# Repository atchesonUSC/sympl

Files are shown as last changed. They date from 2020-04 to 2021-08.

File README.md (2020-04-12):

# TaCL
TaCL project source material

Directories:

------------------

1. code_base

Contents:

1. BlocksToLogic.py - Interprets NFC-transmitted data to block logic.

2. LogicToProgram.py - Interprets block logic file created in BlocksToLogic.py, formats program file in C.

3. CompileUpload.py - Compiles the C file, flashes onto Arduino board.

4. variableClass.py - Variable representation class, provides scoping functionality for variable appearances in program.

5. Main.py - contains main program loop and operations.

6. CheckLogic.py - Contains error-scanning features that analyze the block logic file for potential errors.

--------------------

2. Training Modules

Contents:

1. TO BE COMPLETED

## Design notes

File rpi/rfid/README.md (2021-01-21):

# Overview

This repo contains the code for handling management of RFID readers
from the raspberry pi.

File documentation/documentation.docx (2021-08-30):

An Exploration into the Role of Touch in Computer Programming

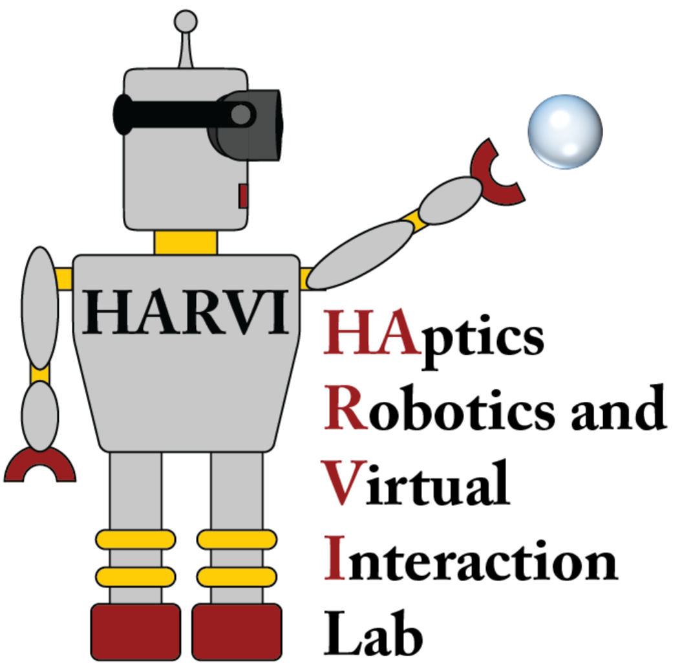
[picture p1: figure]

Official Project Documentation

Organization: HaRVI Lab

Director: Heather Culbertson, PhD

I. Preamble

Welcome! The purpose of this document is to provide an overview of our tactile coding project. Namely, it will cover the locations of project resources, materials, and will detail the remaining assembly required for project completion. The document is organized into three major sections: Overview, Resources, and Assembly. The Overview section will offer a description of the project as a whole and its intent. The Resources section details the locations of, and other sources of documentation for, project components. Lastly, the Assembly section will highlight the current state of the project and will cover the remaining steps for finishing the implementation of the project.

If at any point you should have questions regarding the content of this or other project documentation, please don’t hesitate to reach out to either Heather Culbertson (hculbert@usc.edu) or Alex Atcheson (saatcheson@gmail.com) for clarification or assistance.

II. OVERVIEW

In this section, we will briefly discuss the goal of the project and the programming tool under construction. Moreover, we will cover the workflow that programmers will encounter when using the novel programming tool.

The genesis for this project is all about understanding the role that touch may play in computer programming. Namely, we are interested in exploring how individuals code through when tasked with using a tactile tool in place of digital text as a representation of computer code. As such, we have devised a novel programming environment whereby programmers use physical coding blocks, each representing a unique code construct, for writing functioning computer programs. Each of these physical coding blocks are 3-D printed elements, about the size of one’s palm, and are consist of a 3-D design on their surface. Via recognition of surface design features, programmers might rely on touch-related stimuli for informing coding practice, an anticipated question of this project.

The system functions as follows: A user would sit down at a desk with the programming tool resting on the desk in front of them. The programming tool is a box shape and can be easily reached in the sitting the position. Next to the box on the table are a variety of coding blocks that the individual can use for writing their own program. Once ready, the individual can begin placing the coding blocks on the interactive area of the programming tool in a sequential order, nearly identical to how one would write text-based code. Once the individual has written completed their program by arranging the coding blocks on the interactive space of the programming tool, they may press the programming tool’s “Run” button for executing their program.

One of the potential target audiences for a tool such as this would be for those individuals who experience some form of visual impairment, lending added difficulty to the task of coding. As such, the programming tool uses non-visual output as a method for signifying successful or unsuccessful program execution, removing the need for sight. To support non-visual output, the programming tool relies on a speaker system for conveying messages and auditory signals to the programmer.

In summary, the system flow would allow for programmers to write code by arranging physical coding blocks on the interactive space of the programming tool. When ready to execute, the programmer may press the programming tool’s “Run” button. Through the internal speaker of the programming tool, the programmer will be alerted of either successful program completion or of an error in their code.

III. RESOURCES

In this section, we will highlight the various materials associated with the project. Namely, we will cover location and organization information. The Assembly section will cover construction steps for completing the project; as such, any build-related information will not be covered here.

High-Level Description

The programming tool works using a combination of hardware and software features. The programming tool has been designed and built entirely from scratch, which means that the hardware and software elements have been curated for the purposes of the programming tool. The below subsections will offer a breakdown of these hardware and software elements.

GitHub

The GitHub repository, titled sympl, houses all the non-hardware project materials. This includes items such as source code, technical drawings, design files, user study design, and Raspberry Pi configuration files. A pointer to the repository can be found here: https://github.com/atchesonUSC/sympl.

To clone this repository onto your local machine, you can click the green “Code” button on the repository home page, copy the SSH or HTTPS link to your clipboard, and run the following command from your command line to clone the repository folder to the directory of choosing:

$ git clone git@github.com:atchesonUSC/sympl.git

Repository Breakdown

The root of the repository consists of a README file and several directories. For increased clarity regarding the structure of the directory hierarchy, each directory consists of a README file describing its contents and related purpose. Please refer to these README files for getting sense for the contents of each directory.

1. design
  a. 3d_print
    i. gcode

Source code files for printing blocks on the Prusa extrusion printer.

  b. laser_cut

Files for upload to the Glowforge application for cutting.

  c. cad

All CAD files for the programming tool and physical programming blocks.

  d. tech_drawings

Technical drawings of the board components containing dimension information.

2. documentation

Informational material on the project.

  a. pics

Project pictures and related media.

3. old

Decommissioned materials, not in use.

4. rpi

Materials related to configuration and setup of Raspberry Pi.

  a. overlays

Device tree patches that allow for adjusting the number of available SPI chip selects.

  b. rfid

Source code for testing reading and writing capabilities of RFID reader configurations.

  c. wifi

Stores wpa_supplicant.conf files for connecting Raspberry Pi to wireless network, useful if using headless Raspberry Pi (i.e. without connecting the Pi to a computer monitor and solely operating from the command line via SSH).

5. samples

Old examples for testing the block code parser; however, these are a bit outdated and not super useful.

6. source

Contains all the source code for making the programming tool operate! main.py is the key file for running the programming tool. ParseTool.py is the second most important file, and is responsible for parsing the block code, catching and reporting errors, and formatting the lines of Python code to be written to an output file (which will be executed – this is the Python translation of the block code).

7. study

Contains information for user study design.

Project Box

The bulk of the project hardware can be found in the project cabinet located on the workshop side of the lab space. Here’s an image of the project cabinet (it is the rightmost cabinet located in the background of the image):

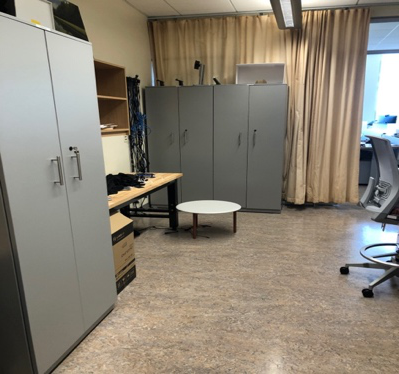
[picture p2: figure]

Upon opening the project cabinet, the project box can be found on the shelf that is second from the bottom. Here is a picture of the cardboard project box:

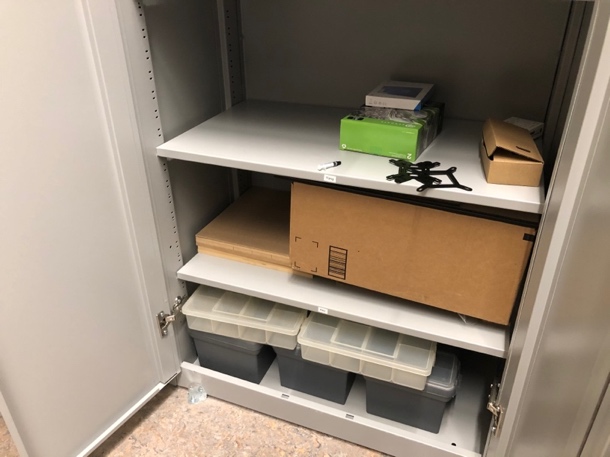
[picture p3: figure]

Other tools that might be necessary for working on the assembly (i.e., soldering iron, 3D printing materials, scissors, etc.) are organized and can be found in the workshop side of the lab space.

IV. ASSEMBLY

This section will cover the remaining assembly required for completing the programming tool. As covered in the Resources section, generally speaking, the materials required for completing the assembly can be found in the project box and the tools for doing so can be found in locations around the lab workspace. The following subsections will cover these remaining assembly steps.

Laser Cut Board Siding

The physical frame of the programming tool is constructed from several pieces of unfinished draftboard. The programming tool is in the shape of a rectangular box, and the layout of the siding is shown below:

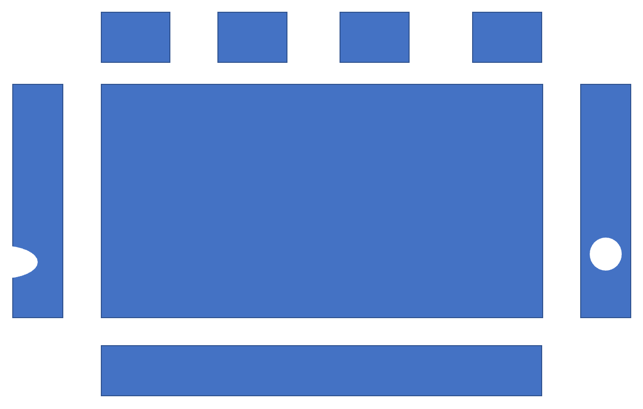
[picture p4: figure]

Of the several box pieces, the top side still needs to be cut. The outward-facing side of the top piece is where users will place and arrange blocks, whereas the inward-facing side is where the sensors and stability components will be connected. The stability components in this case are small magnets arranged on the inward-facing part of the top side. These magnets sit in small casings, as per following image:

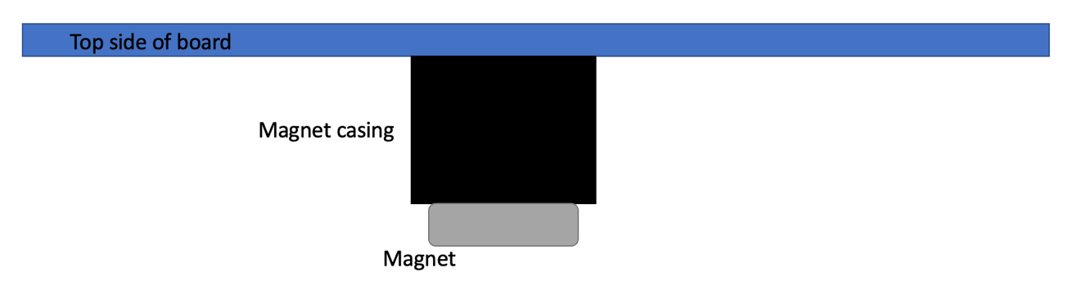
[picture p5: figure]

Located in the /sympl/design/laser_cut directory, there are two SVG files: top_side_upward.svg and top_side_inward.svg. Using a piece of draftboard from lab, the top portion of the board can be laser cut using the Glowforge (check in Sandeep for how to complete the Glowforge training). The Glowforge web app (app.glowforge.com) is where designs can be uploaded for lasering with the Glowforge. For top_side_upward.svg, set the oval shapes to be engraved and set the rectangular outline to be cut. Flip over the cut board piece and place back in the Glowforge bed. For top_side_inward.svg, set the circles to be engraved and set the outline to be ignored.

Row Division

The board consists of 4 rows, with each row supporting 6 block spaces. Dividers between the different rows should be added to reinforce the division between the different rows, as in the figure below:

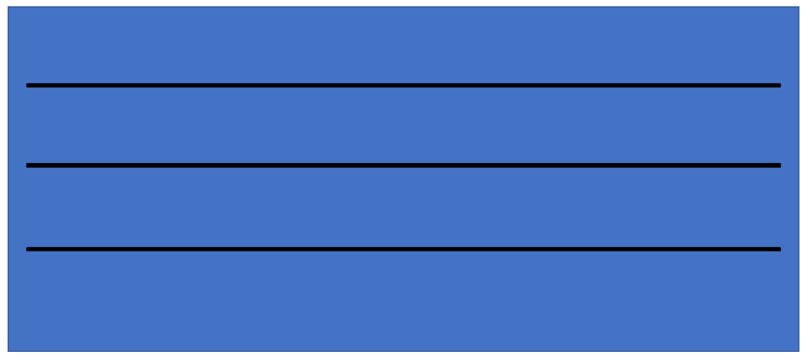
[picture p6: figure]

Three Dowel rods will work well for this, and they can be purchased on Amazon at the following page: - https://www.amazon.com/Wooden-Square-Crafts-Woodworking-Projects/dp/B07T3F18BM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"+square+rod&qid=1625078197&sr=8-4&th=1/

The dowel rods can be cut to the appropriate size and connected to the board (a little bit of hot glue should do the trick here) in such a way to separate the rows as shown in the above figure.

RFID Readers

The programming tool utilizes RFID readers to detect the presence of the programming blocks placed on the surface of the tool. One of these RFID readers, with a yellow ribbon cable connected to it, is pictured here:

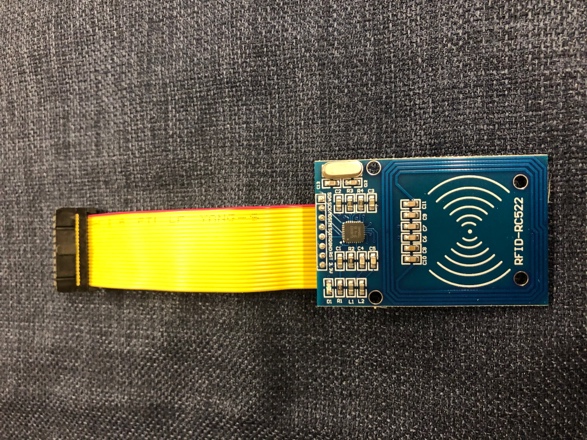
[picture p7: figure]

These RFID readers are connected to the inward-facing side of the top piece of the board box, as shown in the diagram below:

Altogether, since there are 24 total block spaces, there will be 24 total RFID readers connected to the inward-facing side of the top board piece, one for each block space. Some experimentation might be required, but some strong tape should do the trick in the way of connecting the readers to the top piece. The sensing side of the readers (shown in the picture of reader with the white markings) should be facing upward so that it can read the block sitting over its space.

Each of the RFID readers should have a yellow ribbon cable connected to their pins. Ultimately, this will allow for the readers to be easily plugged into the programming tool circuit board (a topic discussed more below).

Programming Tool Audio – Speaker

The programming tool conveys auditory output to the user via a small speaker mounted into the side of the board box. The speaker, along with its connecting cord for interfacing with the Raspberry Pi’s audio port, is pictured here:

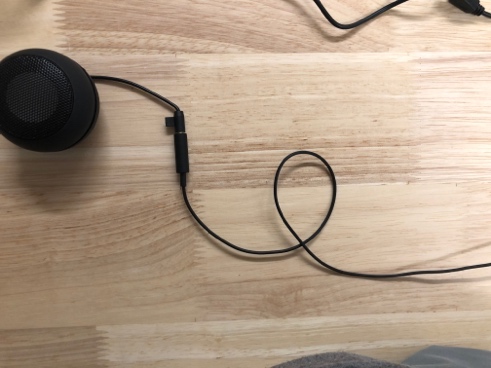
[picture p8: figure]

If twisted, the speaker can extend in length, as in the following image:

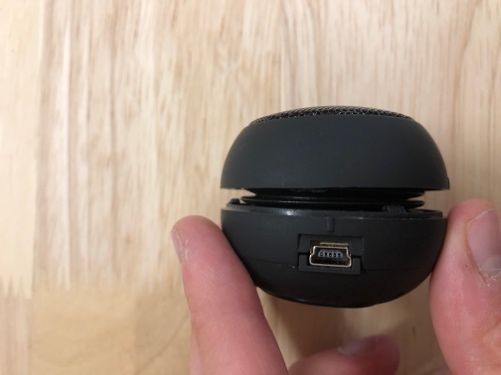
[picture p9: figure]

To insert the speaker into the board box, it is desired that the speaker be untwisted, and box side wedged in between the two ends, so that the audio-emitting portion face outward and the other portion face inward. The below figure gives a view of this design:

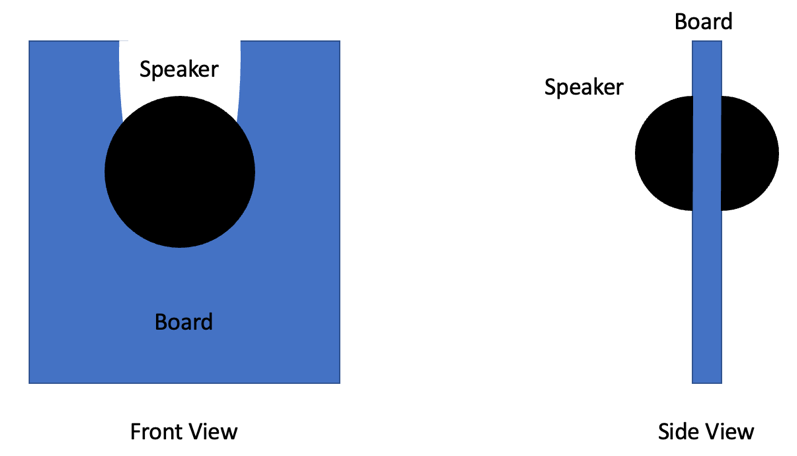
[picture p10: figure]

As shown in the diagram above, the speaker is wedged into the side piece of the board. This wedge opening must be carved out. To do this, you can take a piece of draftboard and, using the Glowforge, cut out the design entitled speaker.svg in the laser_cut folder. Once the piece has been cut, you can carve out the opening to the whole using a dremel tool in lab. This step is pictured below:

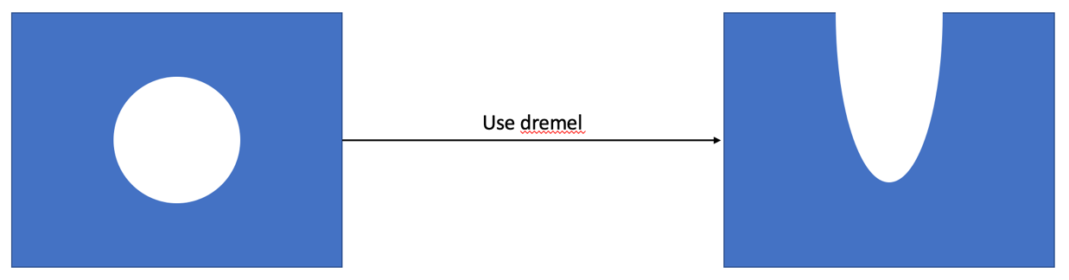
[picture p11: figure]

Magnet Casings

Magnets are used for providing a form of stability and control to block placement. These small magnets are inserted into 3D-printed casings, which are then attached to the inward-facing side of the top part of the board. An image of a magnet in its casing is shown below:

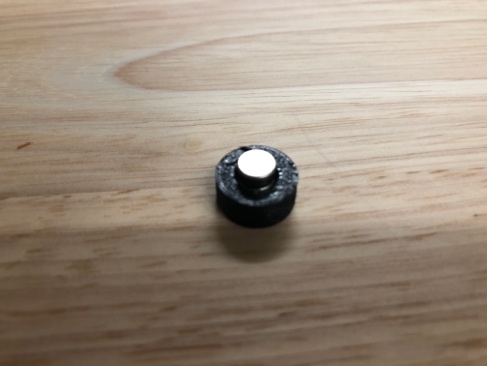
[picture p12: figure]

The magnets can potentially be secured by using hot glue. These magnet casings can be 3D printed in lab using the Prusa extrusion printer. The gcode for the magnet casing can be found in the gcode folder in the 3d_print directory. Once you have downloaded and installed the PrusaSlicer application (useful for 3D printing with our lab’s printer), you can simply use this gcode file. Here’s where you can download the PrusaSlicer tool: https://www.prusa3d.com/prusaslicer/

From the subsection Laser Cut Board Siding, it discussed the engraving process that occurs to the inward-facing side of the top board piece. These engraved holes are where the magnet casings will be connected, as illustrated in the second graphic of that section.

Compile/ Execute Button

The programming tool has a single button for executing code, which is located on the side of the tool. An image of this button is shown below:

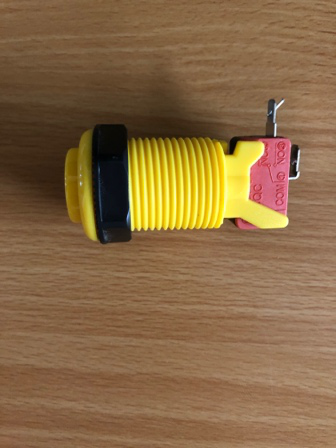
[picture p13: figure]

This button is “normally open,” which means pressing it will close the circuit.

Power Supply

To power the programming tool, it must be plugged into a wall outlet. The plug for the tool is pictured here:

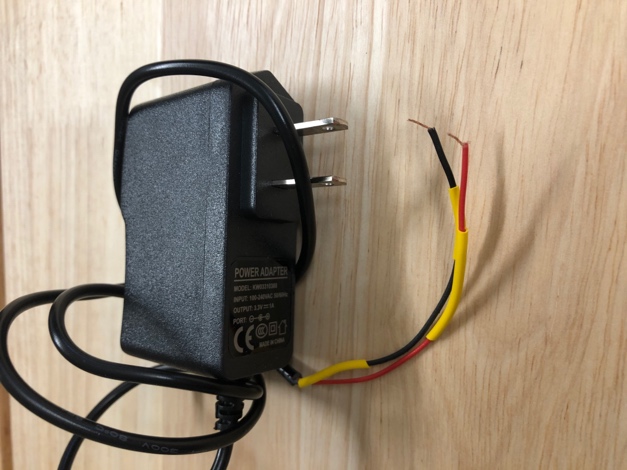
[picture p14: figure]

The red wire is for power and the black wire is for ground.

Circuit Board

The programming tool consists of several electronic components: Raspberry Pi, speaker, button, and RFID readers. The Raspberry Pi is the brains of the tool, the speaker is for auditory output, the button is executing the block code, and the RFID readers are for sensing the type and location of the blocks. Internally, these components are connected to the same circuit board.

First let’s talk about the protoboards that comprise the circuit board. Each protoboard is consists of 30 columns (with label “A” on top and “D” on the bottom) and 48 rows, as shown in the picture below:

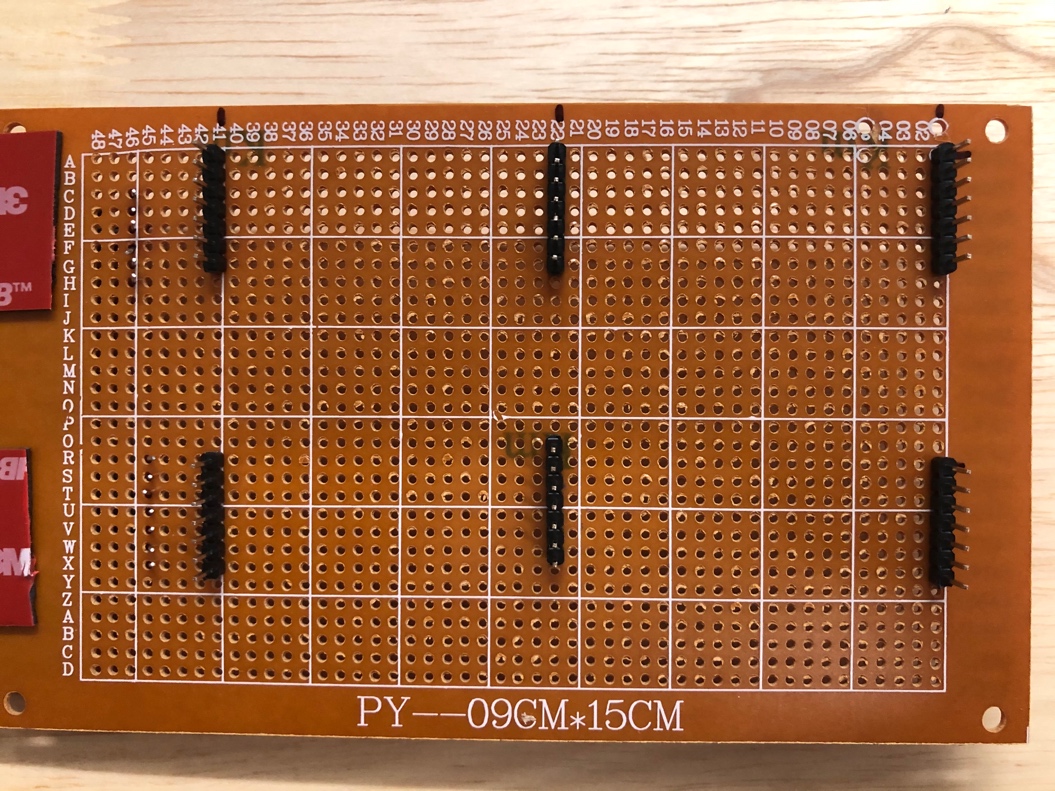
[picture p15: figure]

Each column is shorted to be a single node, meaning that all the holes in a column are connected. This makes it convenient for connecting a row of readers in parallel, where each RESET pin on a reader is connected a column designated for carrying the RESET signal, and so on.

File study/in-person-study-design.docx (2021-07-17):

Tactile Programming – Exploratory Design Evaluation Outline

Spring – Summer, 2021

Research Questions

RQ1: Are there any usability issues that impede students of mixed visual ability from reading code?

RQ2: Are there any usability issues that impede students of mixed visual ability from writing code?

RQ3: How do students of mixed visual ability trace programs?

RQ4: How do students of mixed visual ability create programs?

Participants

Target population characteristics:

- Age: 18 – 23 (Typical age range of college students)
- Major(s)/ Background: Computer Science
- Programming Experience: Participants must identify as having programming experience in some form (No strict definition used here)
- Visual Ability: Sighted (It should be noted that, roughly speaking, a single degree of sightedness should be considered, as this may impact the exploratory/ scanning abilities demonstrated by participants; sightedness controlled using blindfold)

Data Capture and Analysis

Collection strategies:

- Video
  - Camera positioned directly above programming device, facing downward onto device surface.
  - Capture participant hand movements and exploratory motions.
  - No audio capture necessary.
  - Annotations
  - QR code hand tracker
- Compiled programs
  - Store raw block code, compilation success or failure flag, and error message (if any)
    - Per-participant entry created following compilation

Tracing Programs

Working “Trace” Definition: Any physical, verbal, or visual way of describing program execution.

Tracing Sequences

- Purpose
  - Examine ability of users to interpret basic statements.
  - Consider how line continuation may impact readability.
    - Examine continuous assignment statement (all on one line) and statement that is broken across the two lines.
- Performance test:
  - Provided completed code, ask participants to describe the program execution
    - Level 1: “Assign 7 to V1”
    - Level 2: “Assign 2 to V1. Assign sum of 3 and V1 to V2”
- Time Estimate: ~ 5 minutes

Tracing Branching Logic

- Purpose:
  - Examine ability of participants to interpret branch conditions
  - Examine ability of participants to determine which branch will execute given a condition to be evaluated
- Performance test
  - Provided completed code, ask participants to describe the program execution
    - Level 1: “Assign 3 to V1. If V1 greater than 4, assign 8 to V1. Else, assign 5 to V1.”
    - Level 2: “Assign 6 to V1. If V1 less than 4, … Else if V1 less than 7, … Else, …”
- Time Estimate: ~ 5 minutes

Tracing Loops

- Purpose:
  - Examine ability of participants to interpret loop conditions
  - Examine ability of participants to trace looping over several iterations
- Performance test
  - Provided completed code, ask participants to describe the program execution
    - Level 1: “Assign 1 to V1. Loop 5 times, incrementing V1 by 1 each time”
    - Level 2: “Assign 4 to V1. Loop 8 times, incrementing V1 by 2 each time”
- Time Estimate: ~ 5 minutes

Tracing to Debug

- Purpose:
  - Examine ability of participants to find and fix program bugs, both syntactic and semantic
  - Sheds light on helpfulness of auditory feedback (error messages) and the exploratory strategies used by
- NO performance test here, just something to observe/ take note of
  - Specifically, pay special attention to annotate comments/ strategies used by participants to fix problems, also any issues that impede problem solving

Creating Programs

Create sequence

- Purpose:
  - Examine sequence-building patterns of students with mixed visual ability
- Performance test
  - Provided necessary blocks and high-level description, ask participants to write code

Create branching logic

- Purpose:
  - Examine branching-logic-building patterns of students with mixed visual ability
- Performance test
  - Provided necessary blocks and high-level description, ask participants to write code

Create loop

- Purpose:
  - Examine loop building patterns of students with mixed visual ability
- Performance test
  - Provided necessary blocks and high-level description, ask participants to write code

User Evaluation

• Evaluate characteristics of interest for tactile learning tools (refer to Inclusive Education article)

• Request that participants complete the evaluation following all performance testing

Perception | Question | Description
Joy | How fun was the programming environment? | Low values boring, high values fun
Weariness | How tired did you feel when using the programming environment? | Low values tired, high values comfortable
Usefulness | How useful did you find the programming environment? | Low values useless, high values useful
Accessibility | How accessible did you find the programming environment? | Low values inaccessible, high values accessible
Learning | Is the programming environment a good learning tool? | Low values considered bad learning tool, high values considered good learning tool
Potential Use | Do you think this system would have been helpful for you when first learning about topics such as instruction sequences, branching logic, and looping? | Low values indicate would like to use system to learn about basic programming, high values indicate would like to use system to learn about basic programming
Didactic | How didactic (learning with pleasure and entertainment) was the programming environment? | Low values indicate stultifying (stifle enthusiasm, freedom), high values indicate system conveyed meaning and pleasure
Easiness | Did you find the programming environment easy to use? | Low values indicate difficult to use system, high values indicate easy to use system

References

• Torino (https://www.tandfonline.com/doi/pdf/10.1080/07370024.2018.1512413)

• Virtual Haptic Perception as an Educational Assistive Technology: A Case Study in Inclusive Education

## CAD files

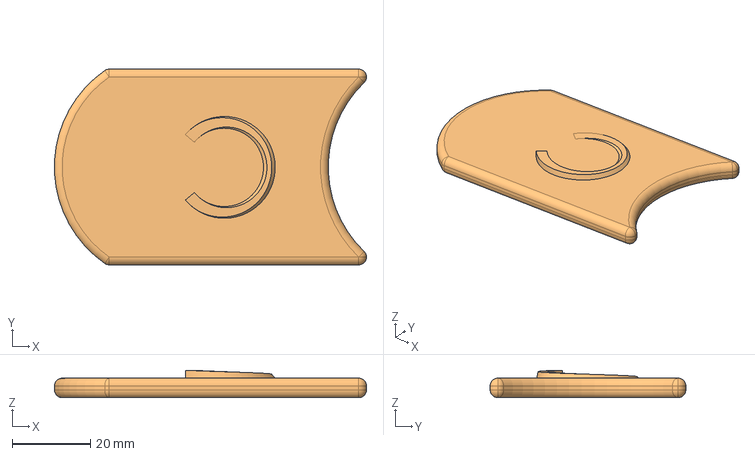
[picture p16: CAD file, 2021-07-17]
design/cad/loopblock.stp
79.7 x 50.0 x 7.00 mm

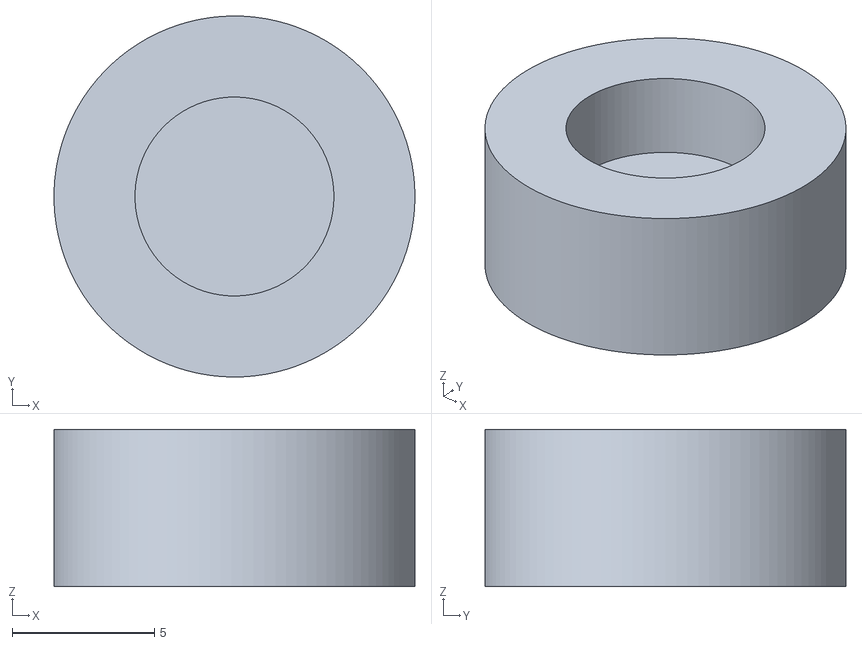
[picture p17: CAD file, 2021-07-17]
design/cad/magnet_casing.stl
12.7 x 12.7 x 5.54

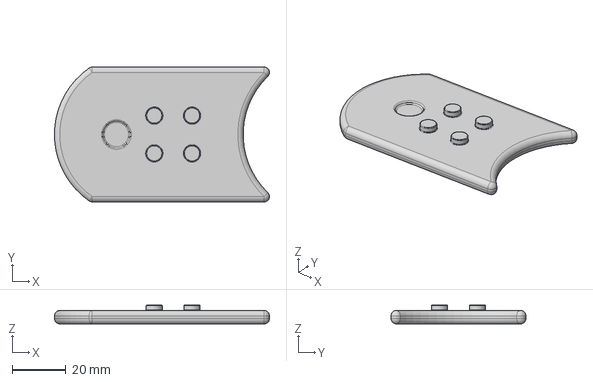
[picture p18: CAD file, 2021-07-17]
design/cad/9block.stp
79.7 x 50.0 x 7.00 mm

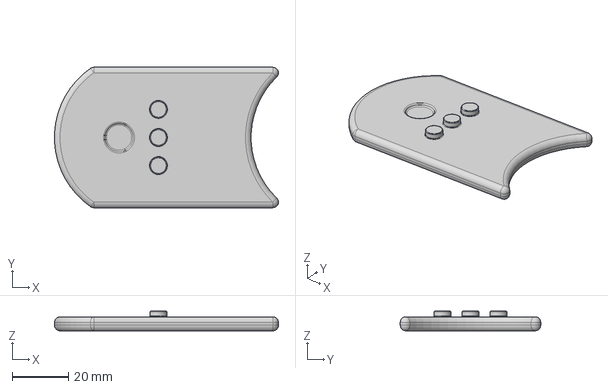
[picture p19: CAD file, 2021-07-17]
design/cad/8block.stp
79.7 x 50.0 x 7.00 mm

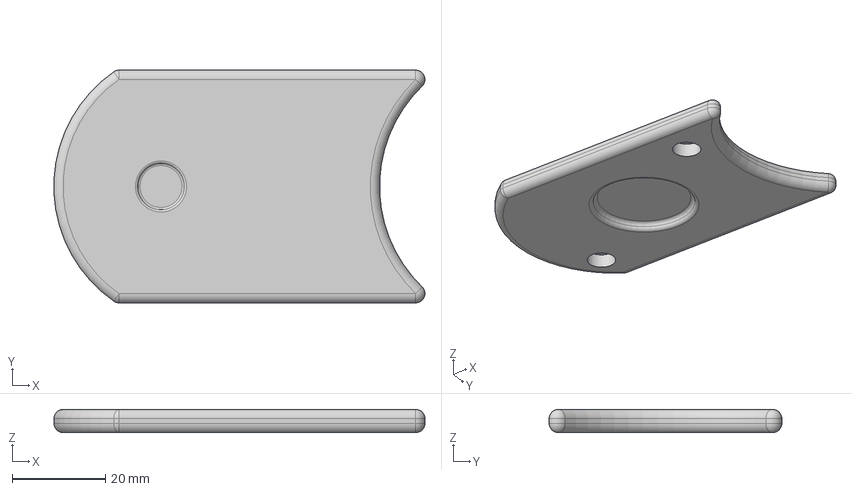
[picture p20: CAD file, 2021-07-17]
design/cad/5block.stp
79.7 x 50.0 x 5.00 mm

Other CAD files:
design/cad/assignblock.stp
design/cad/3block.stp
design/cad/greaterblock.stp
design/cad/endloopblock.stp
design/cad/2block.stp
design/cad/4block.stp
design/cad/elseifblock.stp
design/cad/ifblock.stp
design/cad/stopblock.stp
design/cad/elseblock.stp
design/cad/1block.stp
design/cad/7block.stp
design/cad/6block.stp

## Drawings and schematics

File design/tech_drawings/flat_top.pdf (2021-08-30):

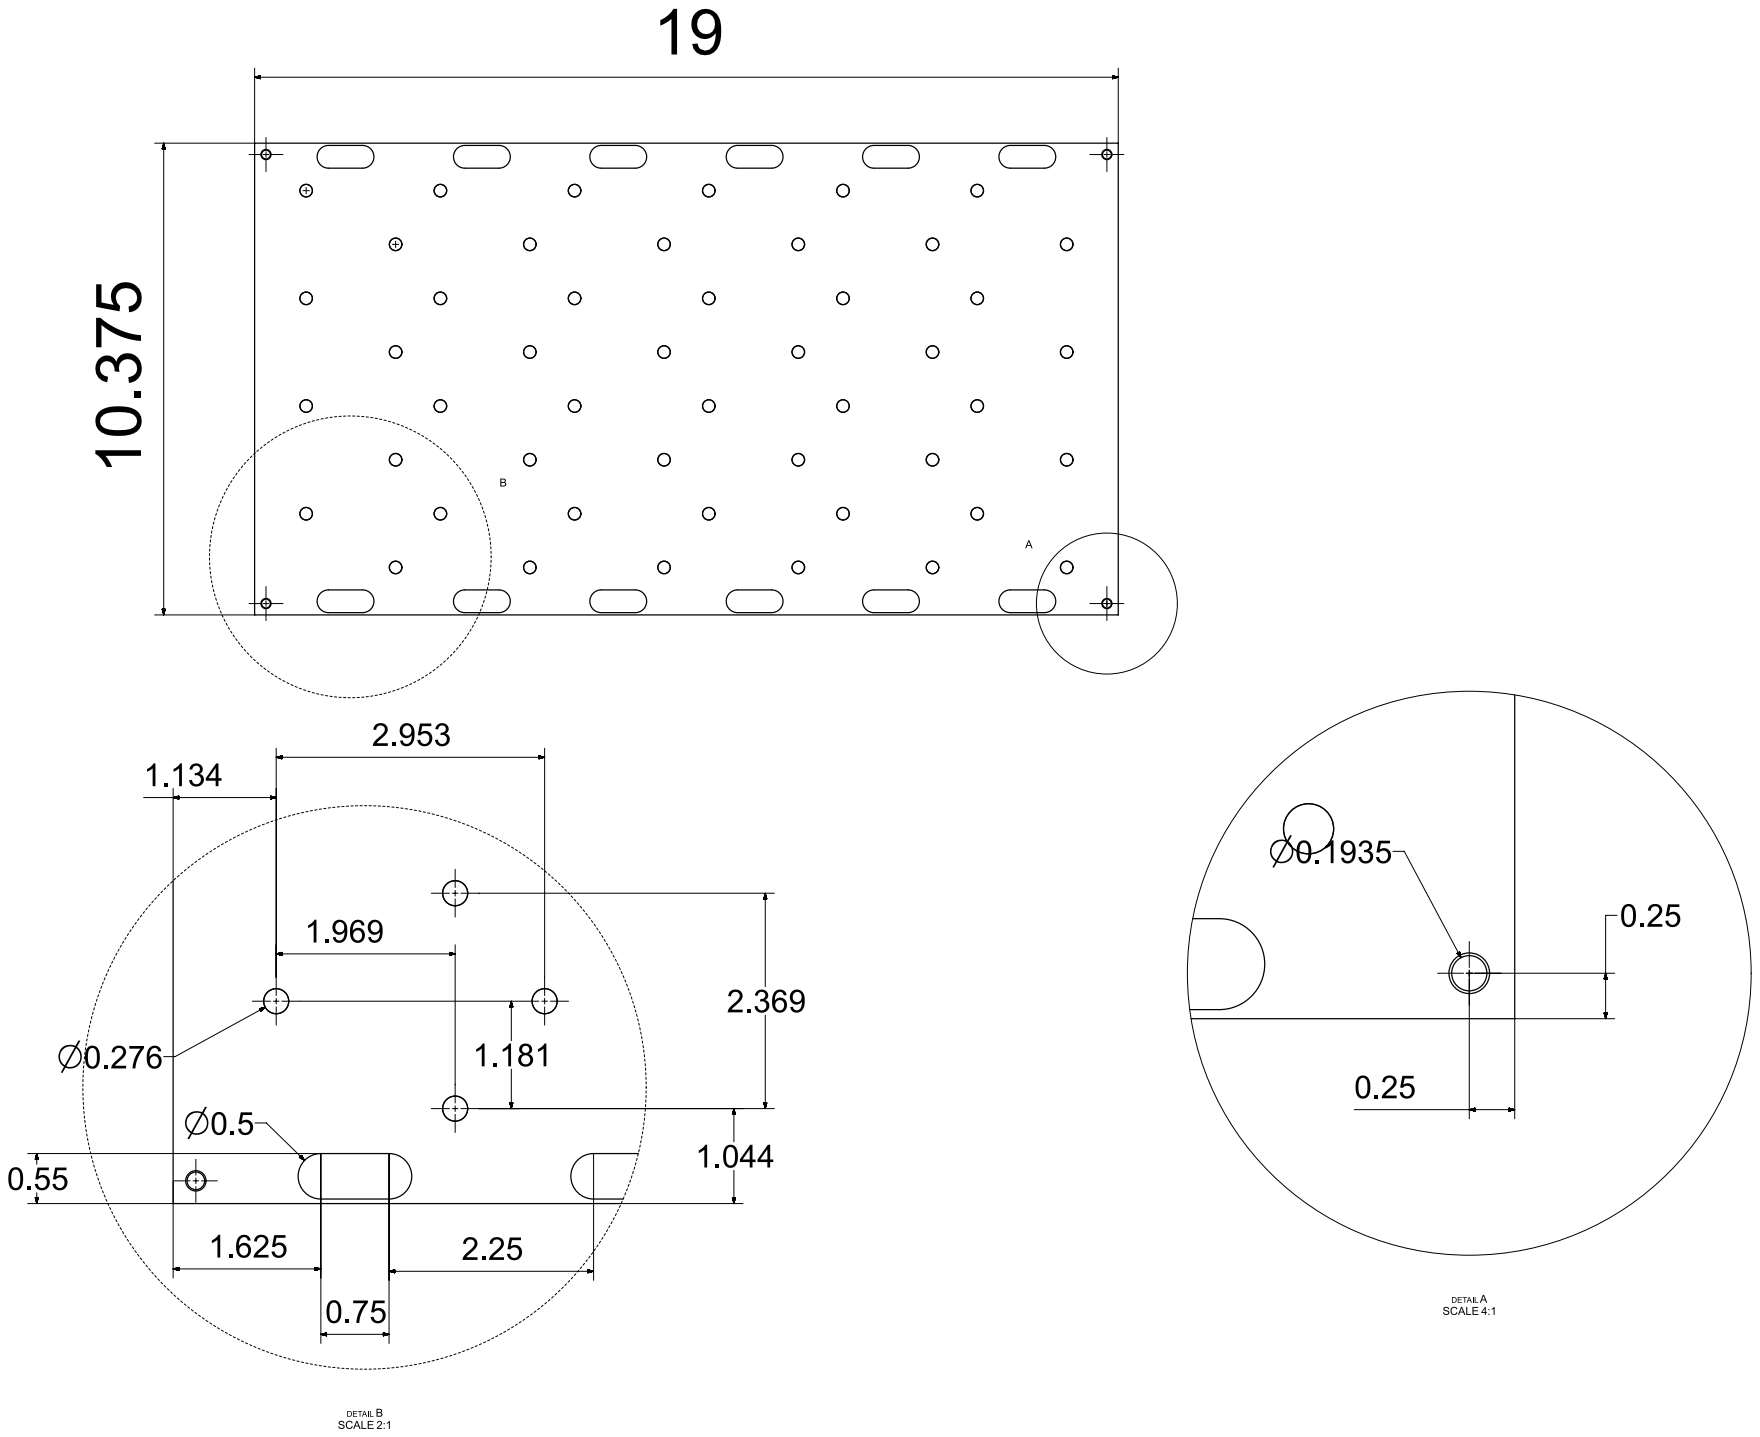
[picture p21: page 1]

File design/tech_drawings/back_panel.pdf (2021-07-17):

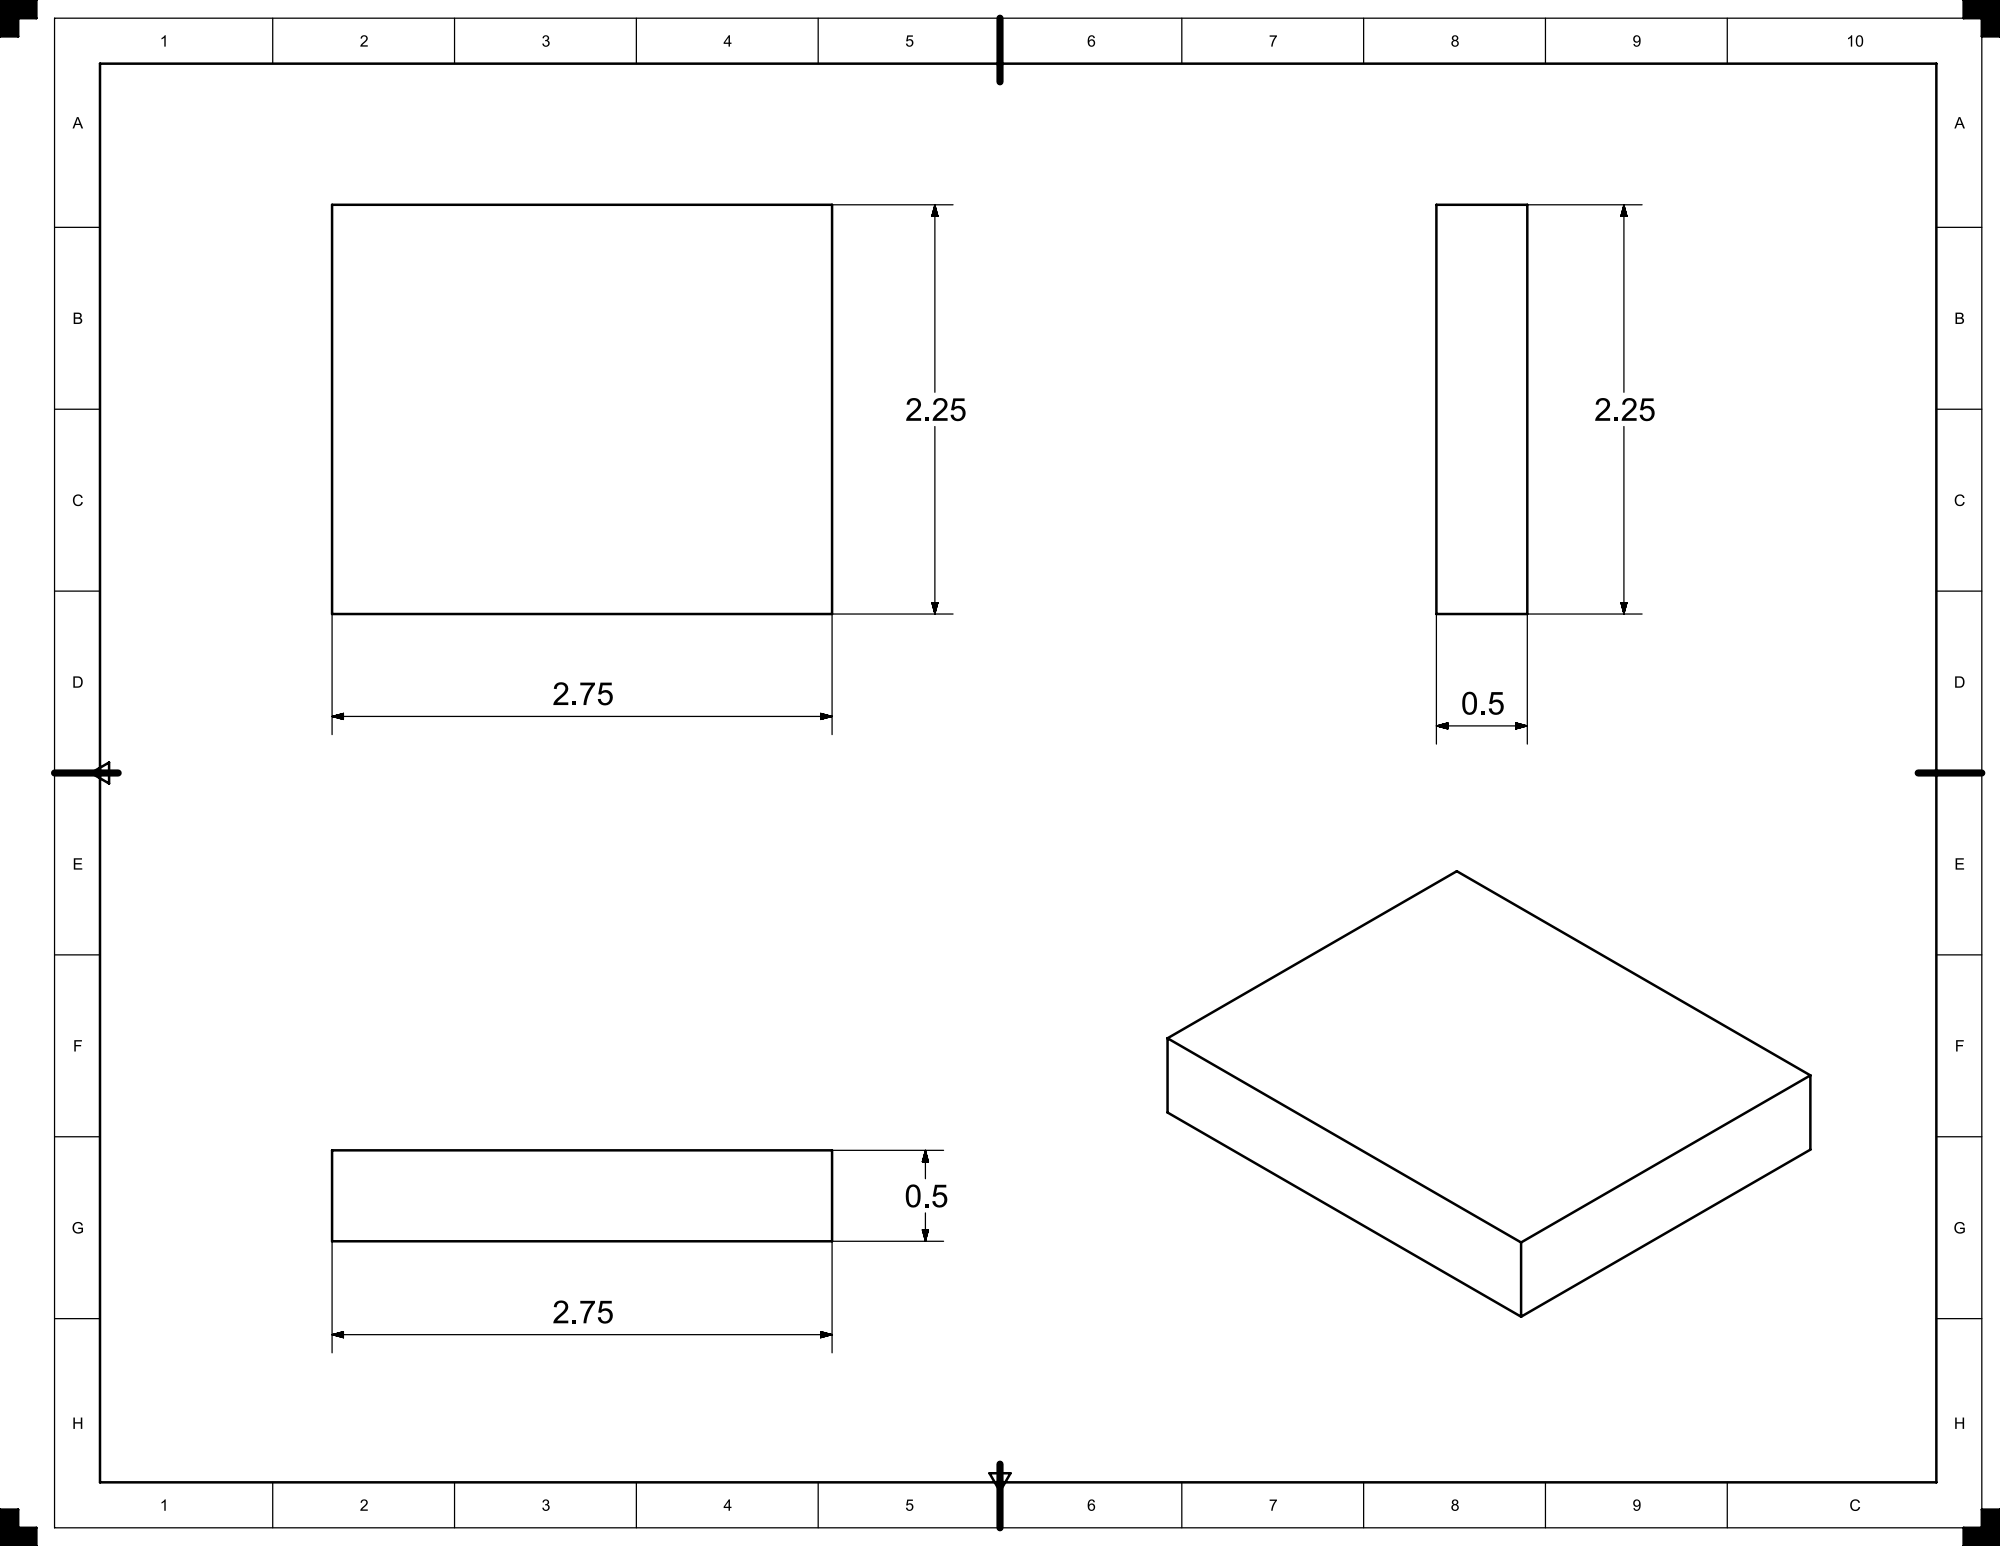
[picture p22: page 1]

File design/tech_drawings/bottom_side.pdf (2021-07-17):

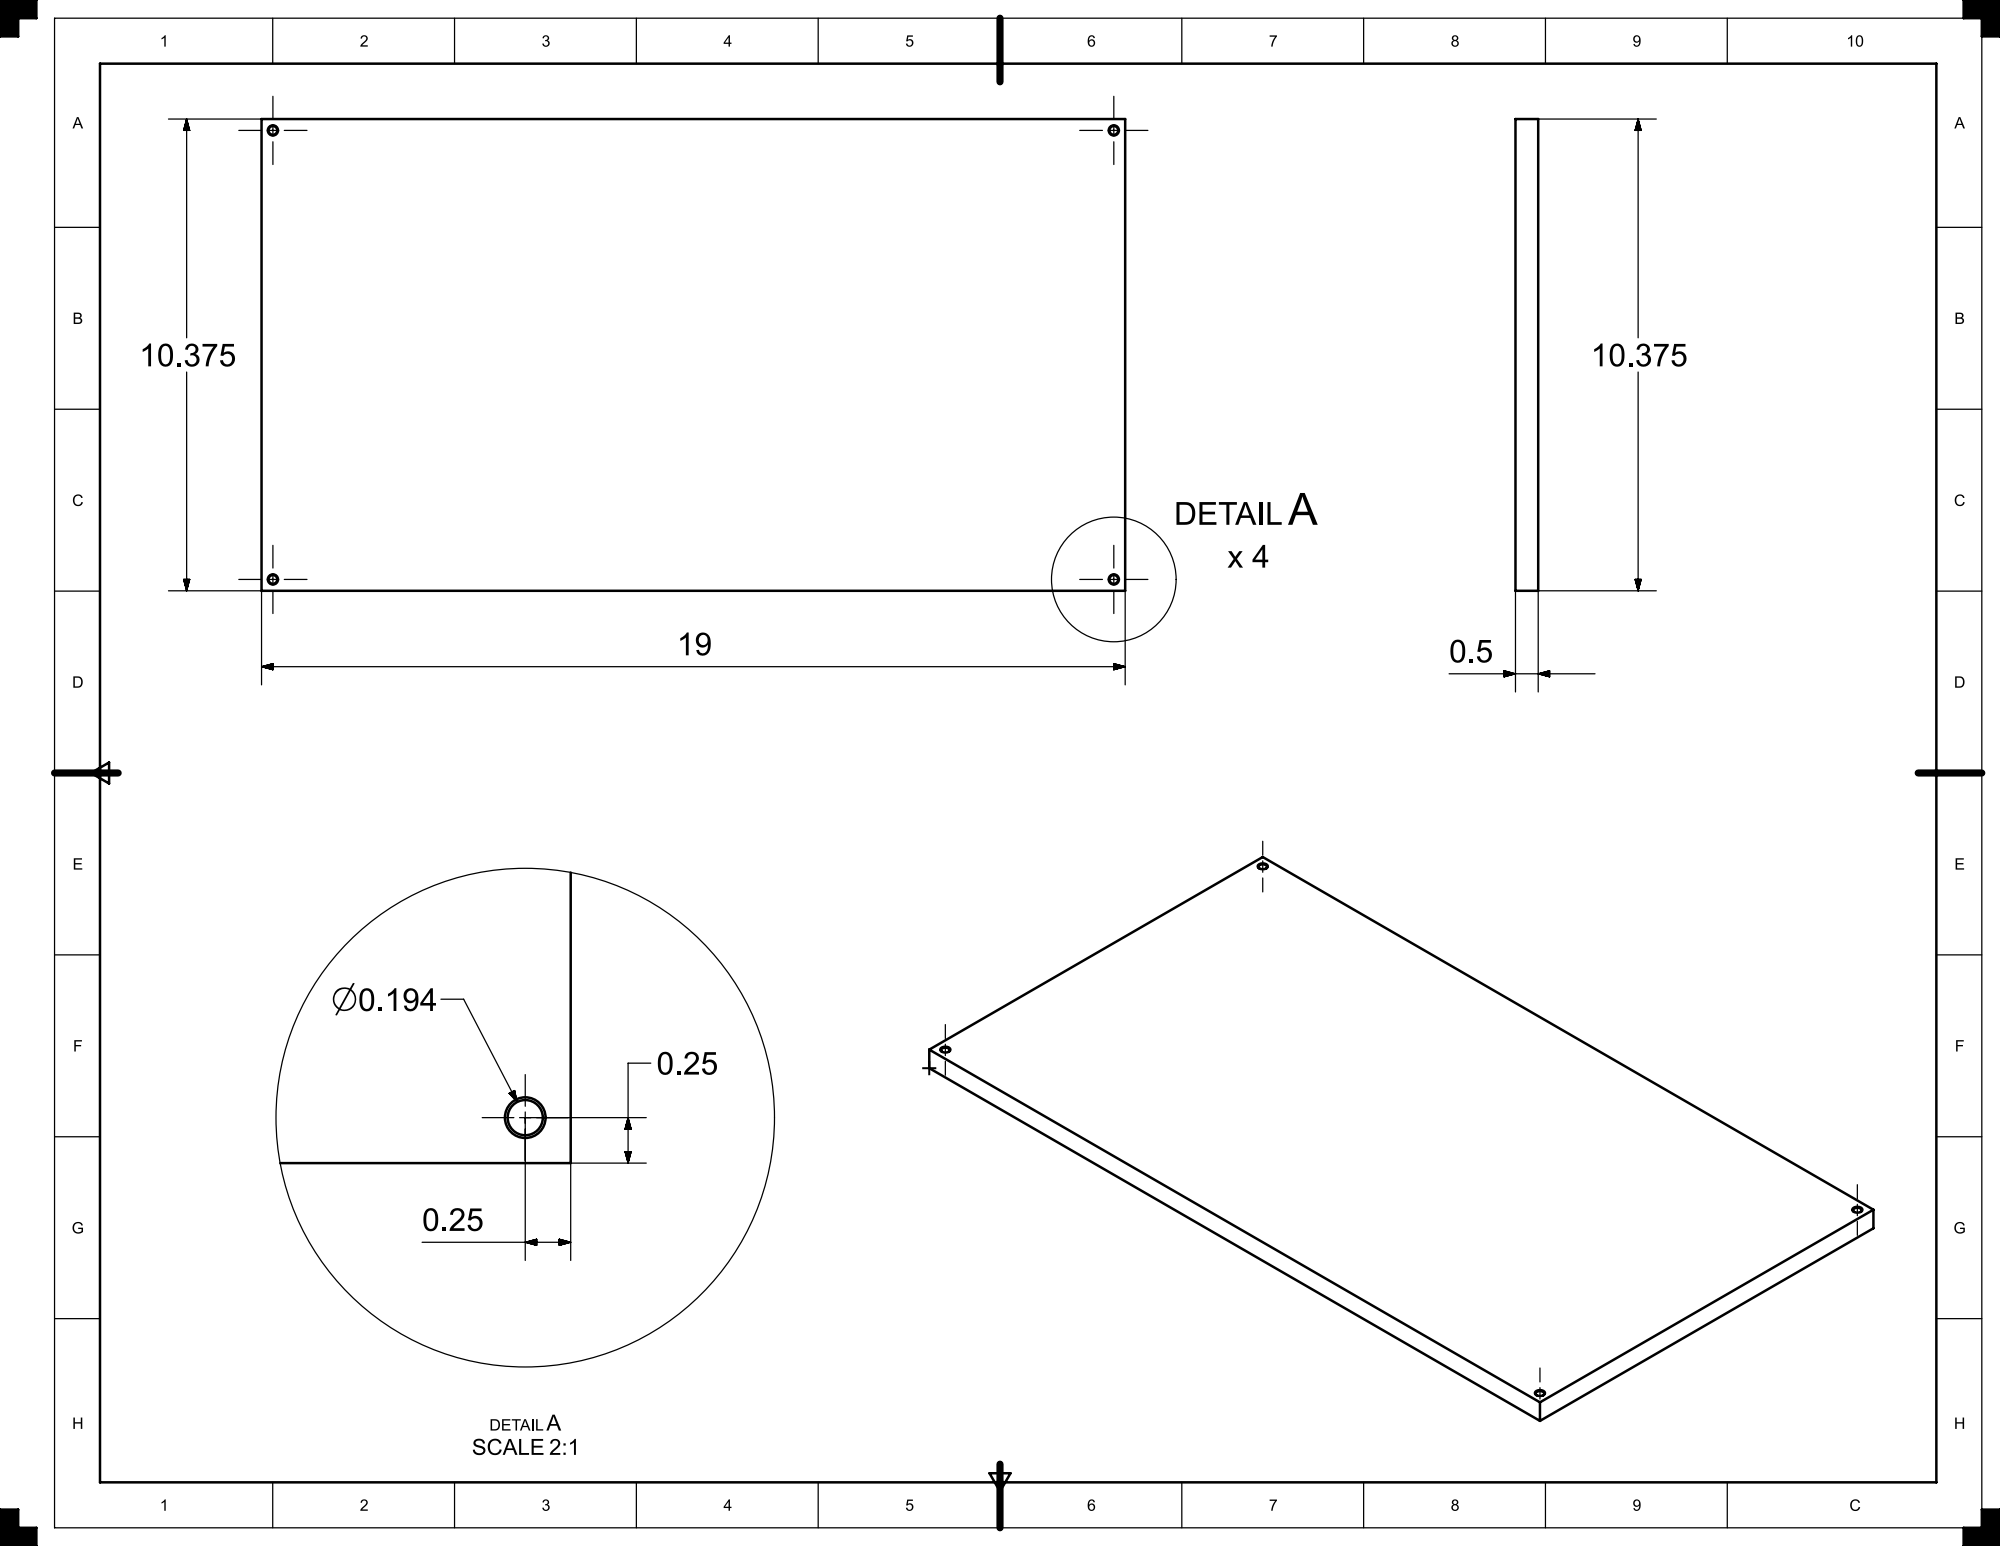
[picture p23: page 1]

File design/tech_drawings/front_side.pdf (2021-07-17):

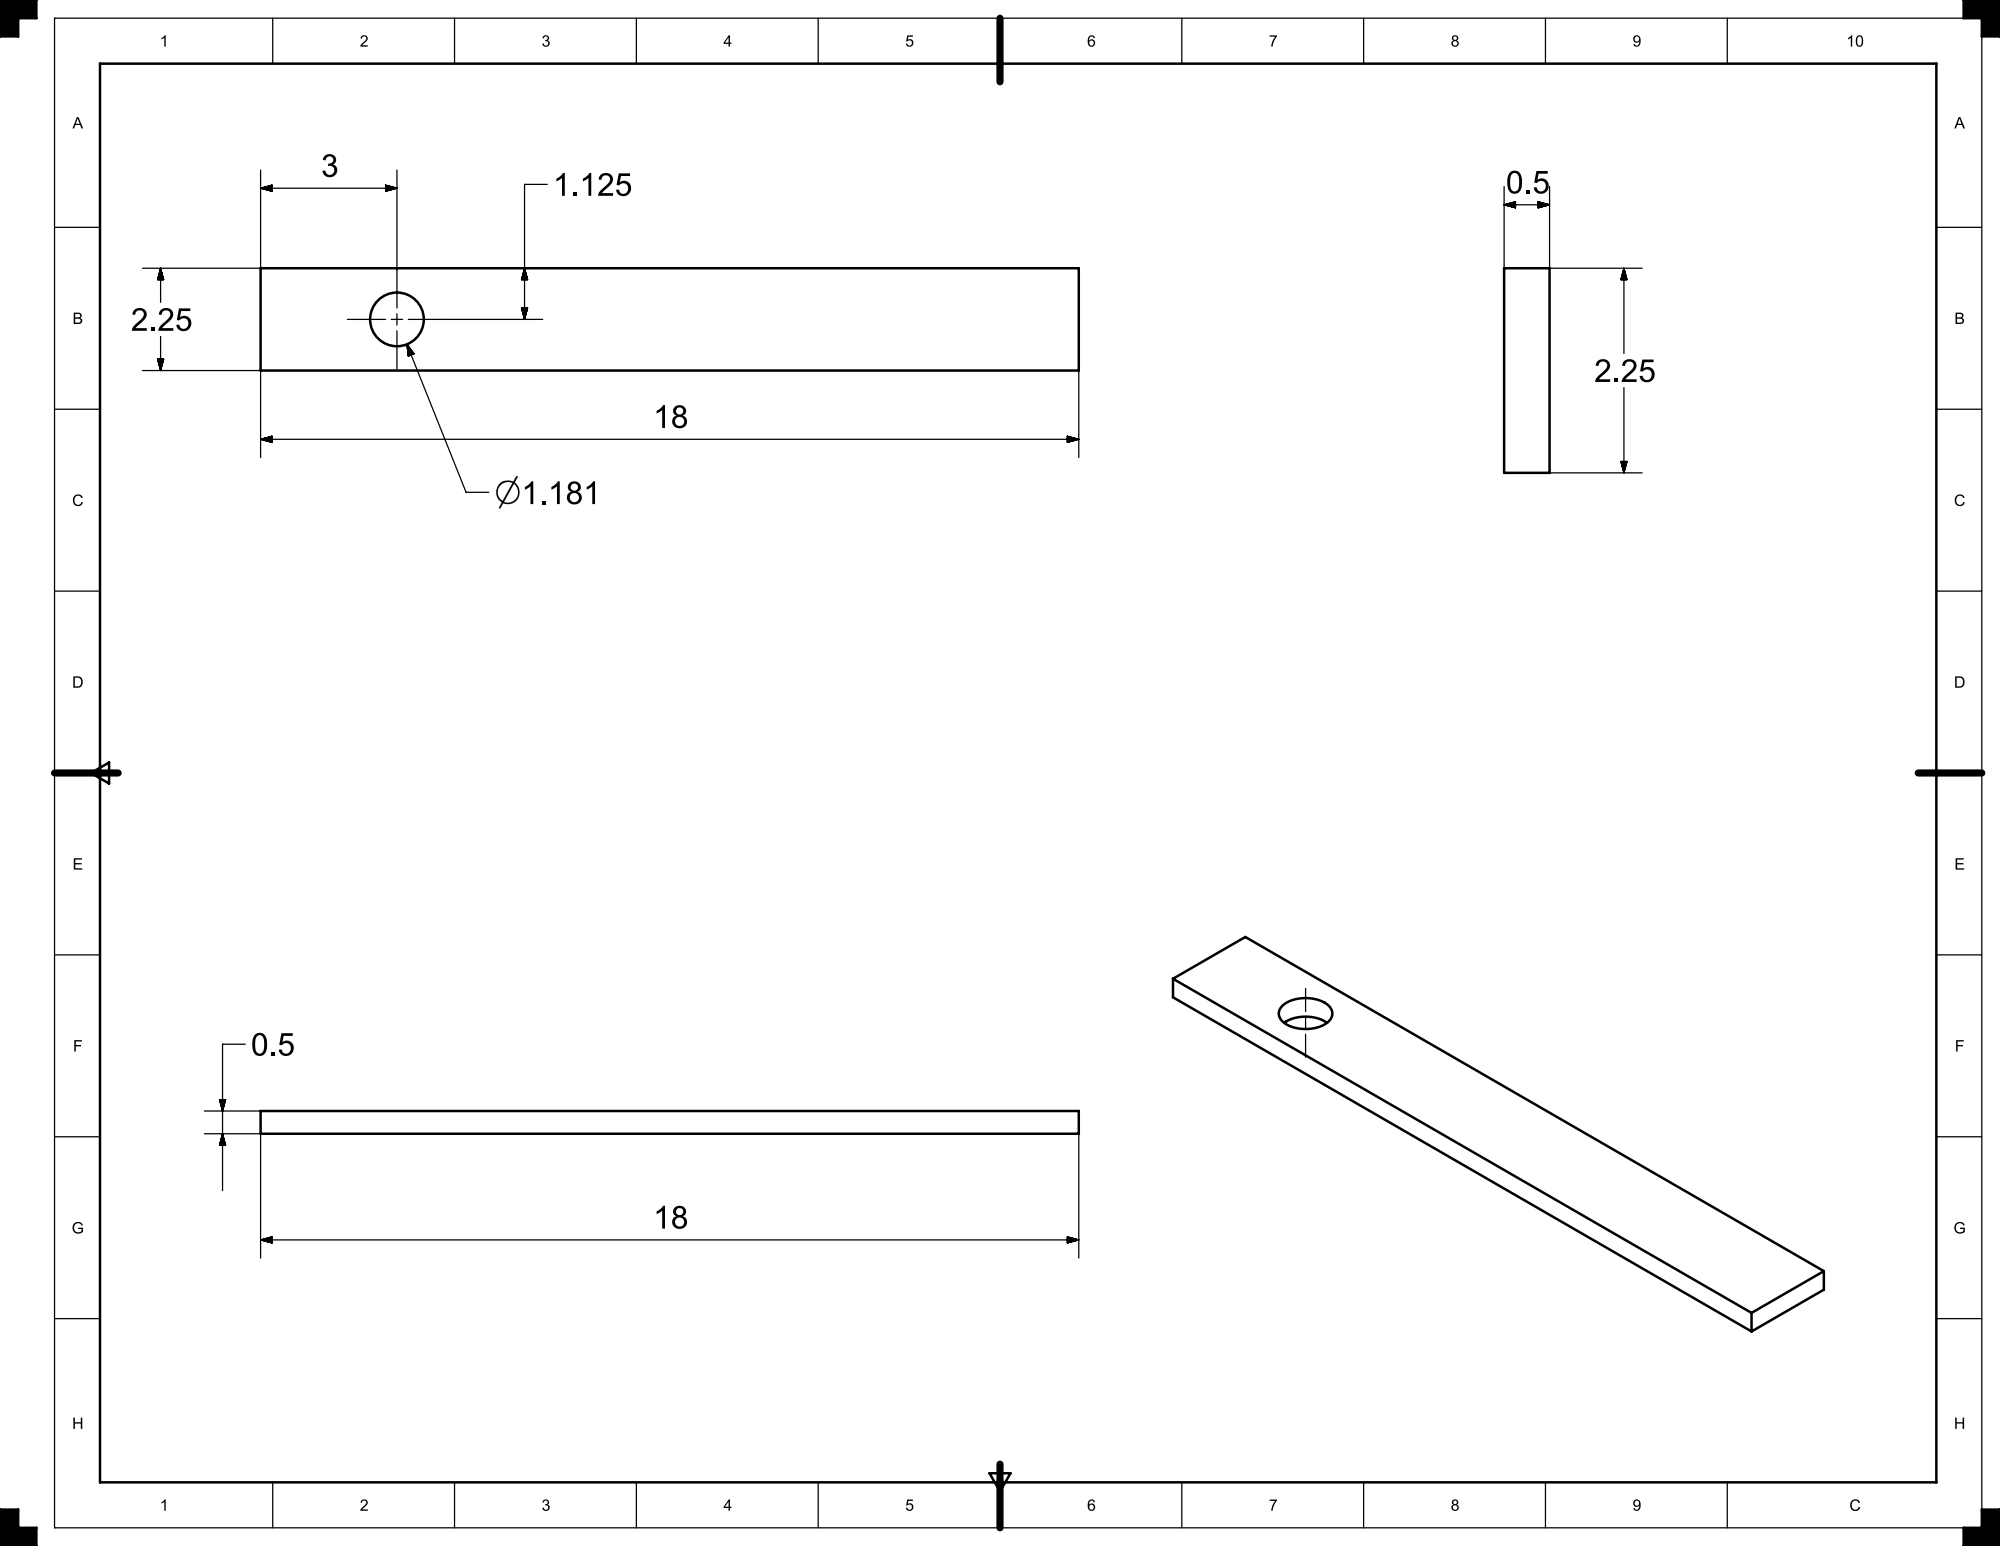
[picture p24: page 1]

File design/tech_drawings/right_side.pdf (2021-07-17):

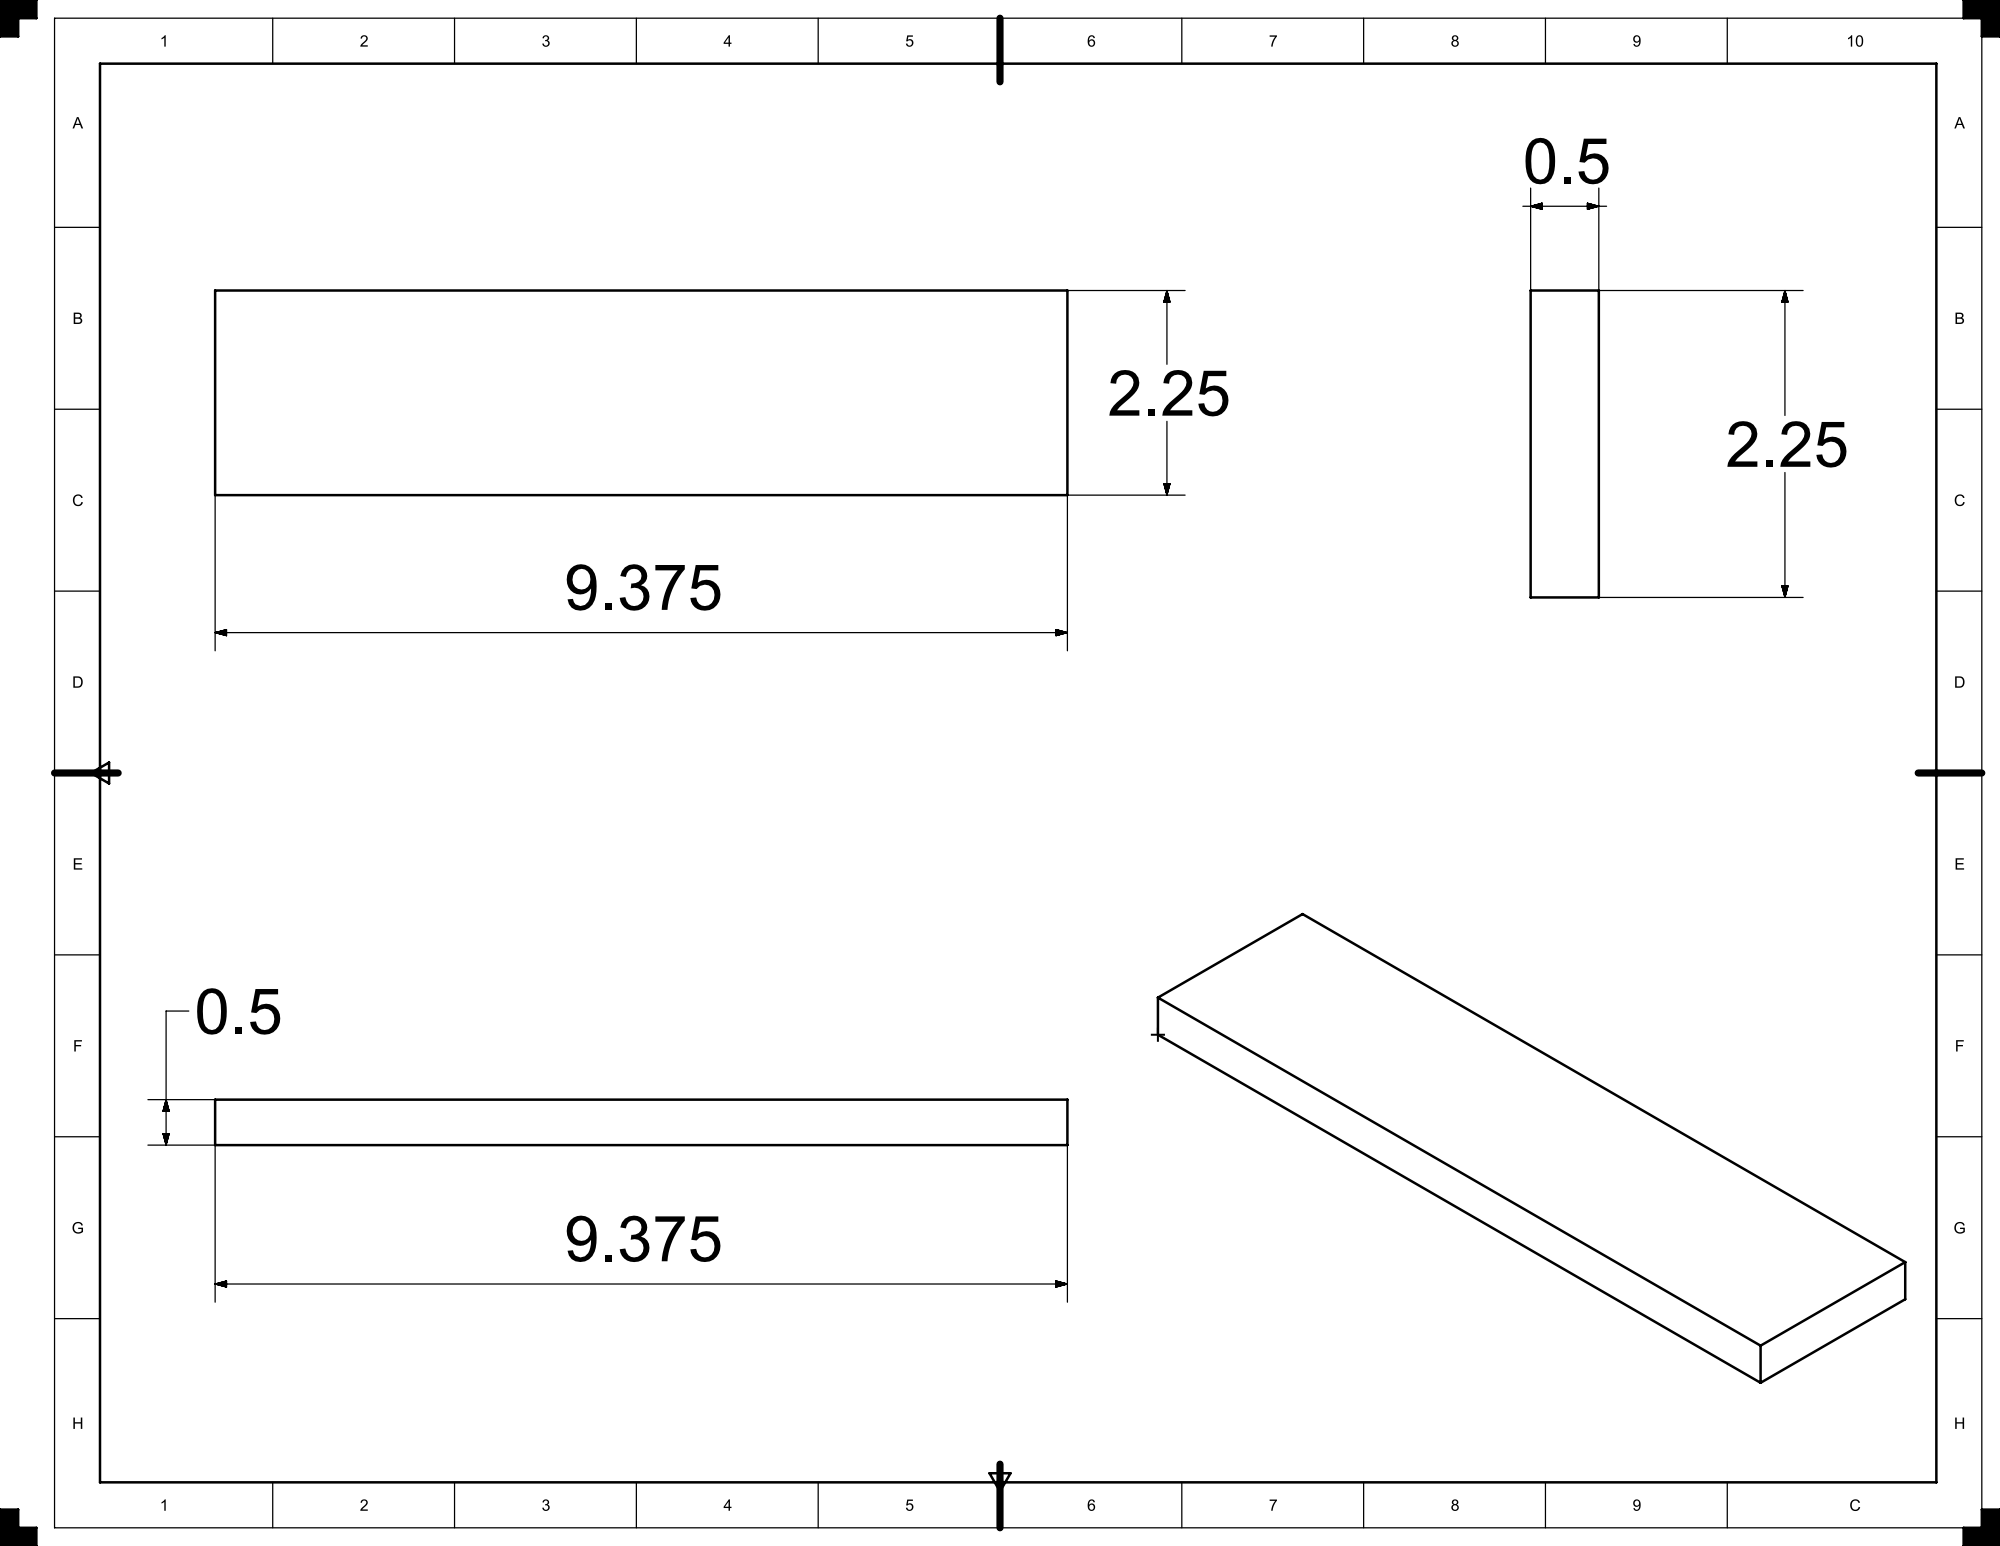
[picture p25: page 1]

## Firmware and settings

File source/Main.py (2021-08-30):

import os
import pin_config
# import RPi.GPIO as GPIO
from ParseTool import ParseTool
# from RfidArray import RfidArray

"""
========================================================================================================
* [main_v2.py.py]: Executes main function for reading each block space, and then converting that block *
*            information into executable code (can choose C or Python formatting of resulting program) *
========================================================================================================
"""

print('===============================================')
print('* HaRVI Lab Software - Tangible Coding Language')
print('* Developer: Alex Atcheson')
print('* Email: saatcheson@gmail.com')
print('===============================================\n')

"""
==================================================================
* [SECTION] Select option for parsing to C or Python source code *
==================================================================
# Specify source file language...
src_code_format = input('[STATUS] Source options: Python (\'p\'), C (\'c\'): ')
while src_code_format.lower() != 'p' and src_code_format.lower() != 'c':
    src_code_format = input('[STATUS] Source options: Python (\'p\'), C (\'c\'): ')
"""

"""
===================================================================
* [SECTION] Create output file for storing executable source code *
===================================================================
"""

# Open output.py file for writing translated Python code
output_file = 'output.py'
ofile = open(output_file, 'w')

"""
==========================================
* [SECTION] Configure input/ output pins *
==========================================
# Configure RPi.GPIO mode...
GPIO.setmode(GPIO.BOARD)

# Configure external device pins...
GPIO.setup(pin_config.SPEAKER, GPIO.OUT)
GPIO.setup(pin_config.BUTTON, GPIO.IN, pull_up_down=GPIO.PUD_UP)
"""

"""
==============================================================
* [SECTION] Read block program from tactile programming tool *
==============================================================
"""
# Array of RFID readers
'''
num_readers = 24
rfid_readers = RfidArray(num_readers)
'''

parser = ParseTool()

count = 0
while count == 0:
    count += 1

    """
    # Wait for Start Button to be pressed...
    while GPIO.input(pin_config.BUTTON) == GPIO.HIGH:
        pass

    # Read block code...
    block_code = rfid_readers.read()
    """

    block_code1 = ['x', '=', '3', 'end', 'if', 'x', '>', '5', 'end', 'x', '=', 'x', '+', '9', 'end', 'end-conditional']
    block_code2 = ['x', '=', '3', 'end']
    block_code3 = ['loop', '5', 'end', 'x', '=', '4', 'end', 'y', '=', '9', 'end', 'end-loop']
    block_code4 = ['x', '=', '7', 'if', 'x', '<', '3', 'end', 'x', '=', '5', 'end', 'elif', 'x', '<', '1', 'end', 'x', '=', '3', 'end', 'end-conditional-structure']
    block_code5 = ['beep', 'end']
    test = block_code5

    """
    ==============================
    * [SECTION] Parse block code *
    ==============================
    """
    # Parse block code to source code
    parser.parse(test)

    # check if any parser errors encountered
    if parser.found_error():
        parser.reset_error()
    else:
        src_lines_processed = parser.format_srclines()

        """
        =======================================================
        * [SECTION] Write formatted source code lines to file *
        =======================================================
        """
        ofile.write('import speaker\n\n')
        ofile.write('# audio and text\n')
        ofile.write('txt = \'beep\'\n')
        ofile.write('audio = speaker.Speaker()\n\n')

        for src_line in src_lines_processed:
            ofile.write(src_line + '\n')
        print('[STATUS] Success! Output file written')

        """
        =================================
        * [SECTION] Execute output file *
        =================================
        interpreter = 'python3'
        output_file_path = '~/sympl/source/output.py'
        os.system(interpreter + ' ' + output_file_path)
        """

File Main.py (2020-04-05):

# IMPORTS!
import serial
import BlocksToLogic
import LogicToProgram
import CompileUpload


# Main Program:
#-----------------------------------------------------------------------------------------------------------------------
def main():
    mappingGuideFile = "BlockMapping.csv"    # Stores block mapping information
    blocks = 16  # Number of board block spaces
    samplesPerBlock = 20    # Number of sample measurements per block space
    vin = 5     # Voltage supplied by Arduino Mega
    boardResistance = 68000   # reference resistor size in board
    serialPort = "/dev/cu.usbmodem14101" # Port for board micro-controller input
    baudRate = 9600
    ser = serial.Serial(serialPort, baudRate)     # Creates a Serial Object - Basically a bridge between program and serial port
    blockData = {"block0":[],      # Stores sample data for each block
                 "block1":[],
                 "block2":[],
                 "block3":[],
                 "block4":[],
                 "block5":[],
                 "block6":[],
                 "block7":[],
                 "block8":[],
                 "block9":[],
                 "block10":[],
                 "block11":[],
                 "block12":[],
                 "block13":[],
                 "block14":[],
                 "block15":[]}
    blockMedianList = []    # stores median value of data set for each block space
    blockPseudoCode = []    # stores logic to be written to .csv file
    blockMappingRange = {}   # stores block mapping ranges for pseudo-code

    while 1:    # main program loop

        while BlocksToLogic.getData(ser) != 3000: # Waits until the start flag is raised
            pass
        outerCounter = 0  # Controls number of sets of data are collected (e.g. data for each block = 1 set of data)
        while outerCounter < samplesPerBlock:
            iteration = 0
            data = BlocksToLogic.getData(ser)
            while data != 2000: # Waits until start flag for block sequence has been received
                data = BlocksToLogic.getData(ser)
            while 1:    # collects single set of block sequence data
                if iteration == blocks:
                    break
                else:
                    BlocksToLogic.readSerialAddToDataset(ser, blocks, iteration, blockData)
                    iteration += 1
            outerCounter +=1

        # Upload mapping data from .csv file and get resistor error range
        BlocksToLogic.sortData(blockData, samplesPerBlock)  # Sort block analog data
        BlocksToLogic.findMedian(blockData, samplesPerBlock, blockMedianList) # Find median value from each set of block data

        # Conduct error inspection for block placement
        placementError = BlocksToLogic.spacingError(blockMedianList, blocks)

        if placementError == 1:
            BlocksToLogic.clearBlockData(blockData)
            blockMedianList = []
            print("Uh-oh! It appears there's an error in your code!")
        elif placementError == -1:
            BlocksToLogic.clearBlockData(blockData)
            blockMedianList = []
            print("Please make sure blocks are connected to the board!")
        else:
            BlocksToLogic.calculateBlockResistance(blockMedianList, vin, boardResistance, blocks)  # Convert analog value to resistance (Ohms)
            BlocksToLogic.resistorError(mappingGuideFile, blockMappingRange, boardResistance)

            # Check each block in blockMedianList and find the range that it belongs to in the blockMapping dictionary
            for block in blockMedianList:
                # print(block)
                for blockType in blockMappingRange:
                    if (block >= blockMappingRange[blockType][0]) and (block <= blockMappingRange[blockType][1]): # checks upper and lower bound of error range
                        blockPseudoCode.append(blockType)
                    # if blockMappingRange[blockType][0] > 0:
                    #     print(blockMappingRange[blockType][0])
                    #     print(blockMappingRange[blockType][1])

            # Write blockPseudoCode to .csv file
            BlocksToLogic.writeLogicFile(blockPseudoCode)

            # Read .csv of pseudo-code and write .c file
            ip_filename = "blocklogic.csv"
            op_filename = "output.c"    # name of created .c file that gets uploaded to external micro-controller
            op_file = open(op_filename,'w')
            ip_data = LogicToProgram.read_file(ip_filename)

            # Conduct error inspection for logic
            # ** Code here **

            # Creates .c file representation of block data
            LogicToProgram.write_main_program(ip_data, op_file)
            op_file.close()

            # Clear block data
            BlocksToLogic.clearBlockData(blockData)
            blockMedianList = []
            blockMappingRange = {}
            blockPseudoCode = []

            # Upload program to Arduino chip
            CompileUpload.compileAndUpload()
# -----------------------------------------------------------------------------------------------------------------------
main()

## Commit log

2020-04-05 Main project files are being added
    [blocklogic.csv]
2020-04-05 added section for error detection in LogicToProgram file
    [LogicToProgram.py]
2020-04-12 restructured directories, updated README
    [blocklogic.csv]
2021-01-31 spi overlay
2021-02-05 add base SPI overlay code
2021-06-23 5cs spi module
2021-07-17 spring cleaning
    [1block.stp, 2block.stp, 3block.stp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]
2021-08-30 spring cleaning, updates to source files for speaker effect
    [blocklogic.csv]
